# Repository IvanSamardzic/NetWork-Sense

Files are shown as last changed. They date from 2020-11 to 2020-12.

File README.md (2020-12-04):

## NetWork-Sense

* Low Power Consumption
* Energy Autonomy
* Wireless Communication Realisation Using Radio Vawes

### System Architecture

GitHub Logo

#### Arduino Nano Pin Configuration

```
const int redLed = 2;
const int greenLed = 3;
const int cePin = 7;
const int csnPin = 8;
const int trigPin = 9;
const int echoPin = 10;
const int mosiPin = 11;
const int misoPin = 12;
const int sckPin = 13;
```

#### ESP32 Pin Configuration

```
const int cePin = 4;
const int csnPin = 5;
const int mosiPin = 23;
const int misoPin = 19;
const int sckPin = 18;
```

#### Network Explanation

The node has the function of monitoring the presence of the object at an angle of 45 degrees, when the vessel / vehicle is recognized by a sensor, then this status change
message is sent to the main node of the sensor network (gateway) using a radio module operating at 2.4 GHz.

When the master node receives a state change message on one of its child nodes, then the gateway sends a request to the database to change the value that determines the
occupancy of the position in front of the sensor.

###### Connection to WiFi Network
```
WiFi.begin(ssid, password);
    Serial.println("Connecting");
    while (WiFi.status() != WL_CONNECTED) {
    delay(500);
    Serial.print(".");
    }
    Serial.println("");
    Serial.print("Connected to WiFi network with IP Address: ");
    Serial.println(WiFi.localIP());
    Serial.println();
    Serial.println();
    Serial.println();
}
```
The gateway is equipped with an ESP32 microcontroller that has the ability to connect to a WiFi network, communicates with the database by sending various HTTP requests.The
ability to send HTTP requests is possible if the HTTP Client is properly created to receive and send data to the HTTP Server.

###### HTTP Client Initialisation 
```
//Send an HTTP POST request every 10 minutes
    if ((millis() - lastTime) > timerDelay) {
    //Check WiFi connection status
    if (WiFi.status() == WL_CONNECTED) {
      HTTPClient http;
    }
    else {
      Serial.println("WiFi Disconnected");
    }
    // Measure the time the system tries to create HTTP Client or
    // time it has been created
    lastTime = millis();
    // Wait for 2000msec
    delay(2000);
  }

```

###### Sensor Data Acquisition And Conversion Into String

```
  digitalWrite(trigPin, LOW);
  delayMicroseconds(delayPeriod/5);
  digitalWrite(trigPin, HIGH);
  delayMicroseconds(delayPeriod);
  digitalWrite(trigPin, LOW);
  duration = pulseIn(echoPin, HIGH);
  distance = duration * conversionFactor;
  Serial.print("Distance: ");
  Serial.println(distance);
  if(distance < distanceLevel){
    digitalWrite(redLed, HIGH);
    digitalWrite(greenLed, LOW);
    isTaken = true;
  }
  else{
    digitalWrite(redLed, LOW);
    digitalWrite(greenLed, HIGH);
    isTaken = false;
  }
```

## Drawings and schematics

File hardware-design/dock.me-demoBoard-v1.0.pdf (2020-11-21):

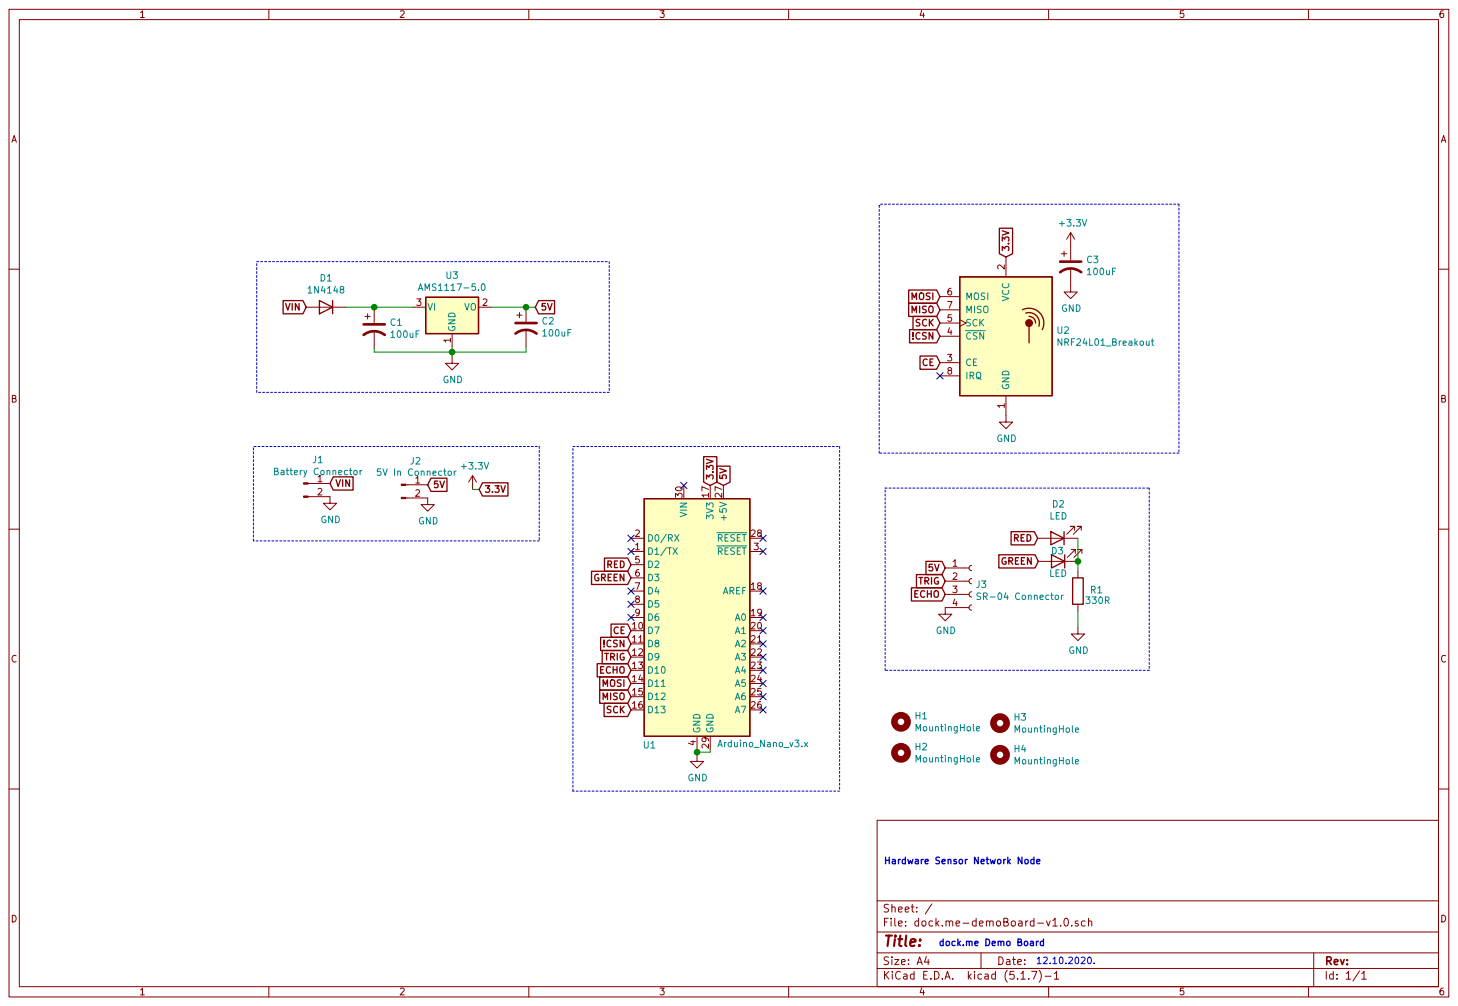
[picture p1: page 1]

12.10.2020. Hardware Sensor Network Node

dock.me Demo Board

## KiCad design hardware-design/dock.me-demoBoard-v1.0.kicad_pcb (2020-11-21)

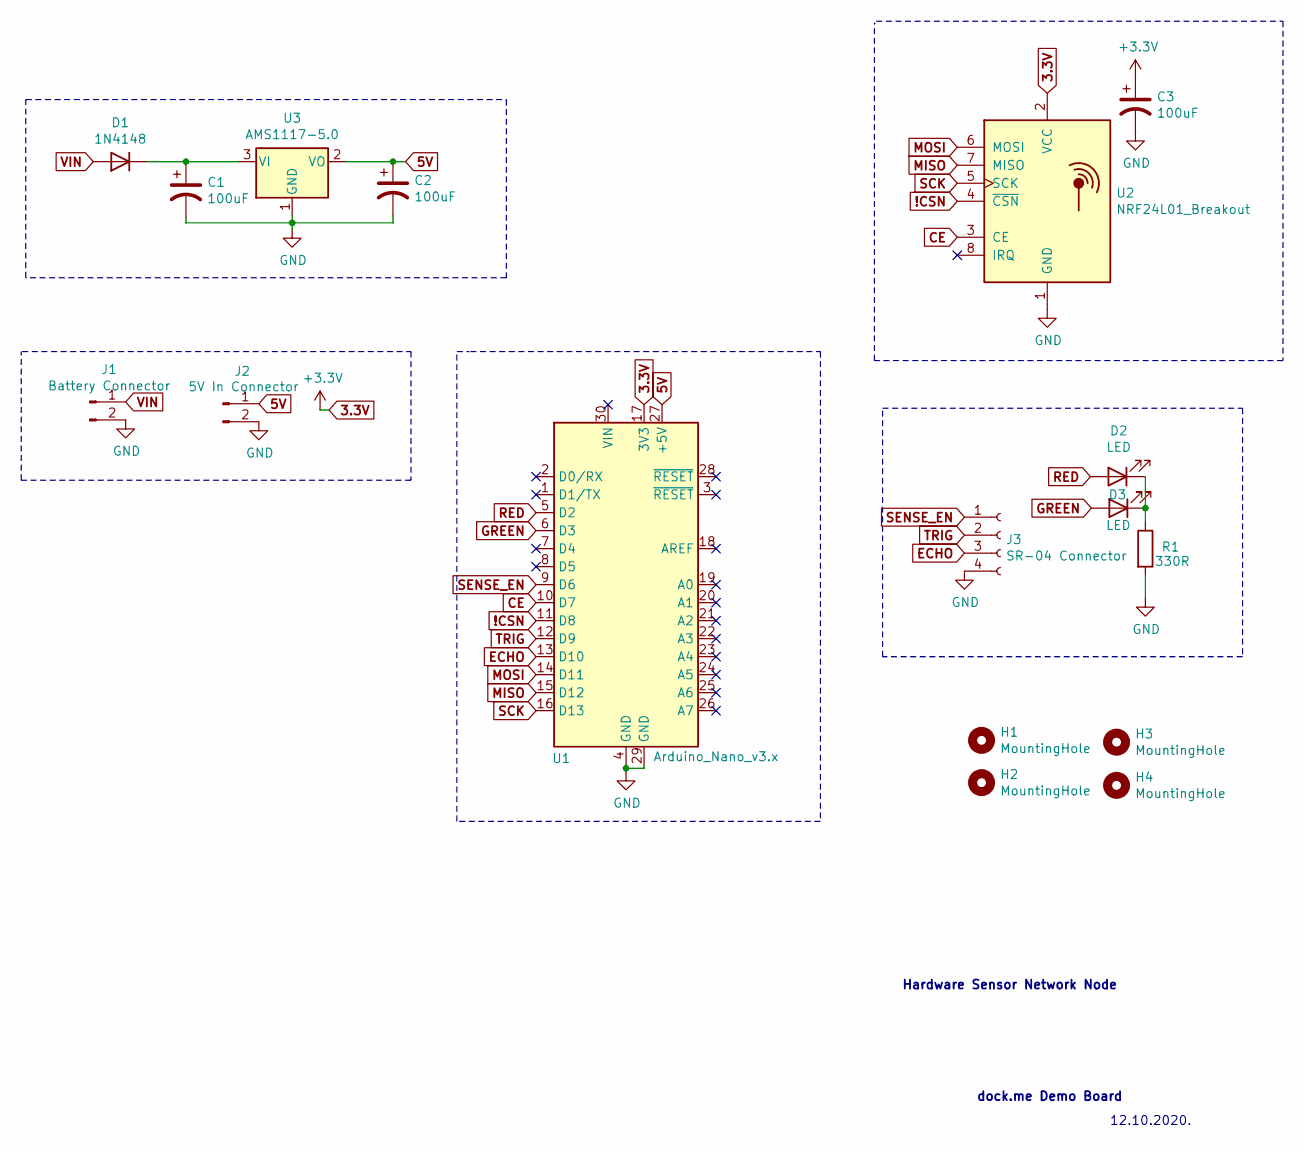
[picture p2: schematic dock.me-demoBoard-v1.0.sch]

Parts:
C1, C2, C3: 100uF; CP_Radial_D4.0mm_P1.50mm
D1: 1N4148; D_DO-35_SOD27_P7.62mm_Horizontal
D2, D3: LED; LED_D5.0mm
H1, H2, H3, H4: MountingHole; MountingHole_2.5mm
J1: Battery Connector; 1x02_5.08mm
J2: 5V In Connector; 1x02_5.08mm
J3: SR-04 Connector; PinSocket_1x04_P2.54mm_Vertical
R1: 330R; R_Axial_DIN0414_L11.9mm_D4.5mm_P15.24mm_Horizontal
U1: Arduino_Nano_v3.x; Arduino_Nano
U2: NRF24L01_Breakout; nRF24L01_Breakout
U3: AMS1117-5.0; SOT-223-3_TabPin2

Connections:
3.3V: C3.1, U1.17 (3V3), U2.2 (VCC)
5V: C2.1, J2.1, U1.27 (+5V), U3.2 (VO)
!CSN: U1.11 (D8), U2.4 (~CSN)
CE: U1.10 (D7), U2.3 (CE)
ECHO: J3.3, U1.13 (D10)
GND: C1.2, C2.2, C3.2, J1.2, J2.2, J3.4, R1.2, U1.4 (GND), U1.29 (GND), U2.1 (GND), U3.1 (GND)
GREEN: D3.2 (A), U1.6 (D3)
MISO: U1.15 (D12), U2.7 (MISO)
MOSI: U1.14 (D11), U2.6 (MOSI)
unnamed: C1.1, D1.1 (K), U3.3 (VI)
unnamed: D2.1 (K), D3.1 (K), R1.1
RED: D2.2 (A), U1.5 (D2)
SCK: U1.16 (D13), U2.5 (SCK)
SENSE_EN: J3.1, U1.9 (D6)
TRIG: J3.2, U1.12 (D9)
VIN: D1.2 (A), J1.1

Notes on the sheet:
dock.me Demo Board
12.10.2020.
Hardware Sensor Network Node

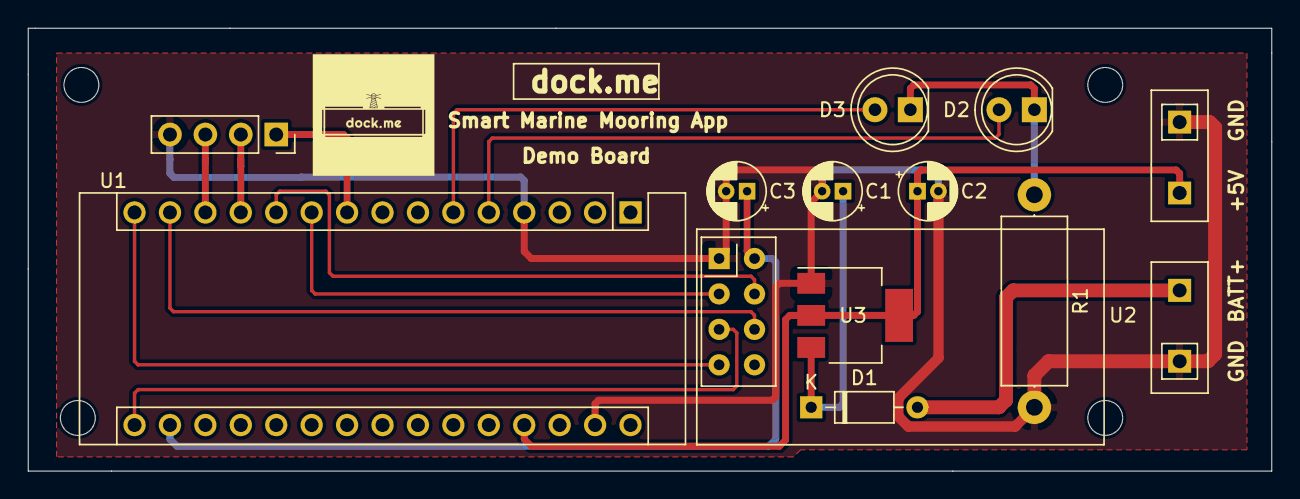
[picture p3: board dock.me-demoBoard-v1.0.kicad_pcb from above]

Board: 2 copper layers, 89.2 x 31.8 mm, 17 parts (0 on the bottom side), 16 nets.

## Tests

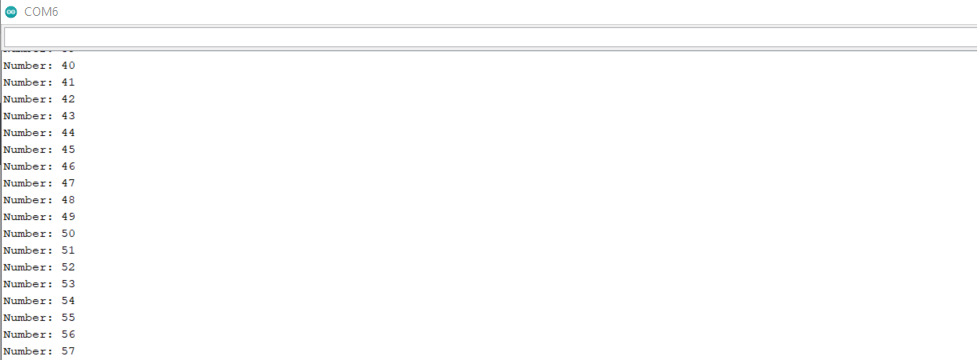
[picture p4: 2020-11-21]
hardware-tests/radio-module-testing/receiver-serial-monitor.png

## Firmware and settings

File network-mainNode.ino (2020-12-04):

// Libraries
#include <WiFi.h>
#include <HTTPClient.h>
#include <ArduinoJson.h>
#include <WiFiMulti.h>
#include <Arduino.h>
#include <SPI.h>
#include <nRF24L01.h>
#include <RF24.h>
#include <WiFiClientSecure.h>

// Pins declaration
const int cePin = 4;
const int csnPin = 5;
const int sckPin = 18;
const int misoPin = 19;
const int mosiPin = 23;

const int timeoutPeriod = 200;


const char* ssid = "Redmi";
const char* password = "174a4bf36308";
RF24 radio(cePin, csnPin);
const byte address[6] = "00001";

//Your Domain name with URL path or IP address with path
//https://dockme20201010041424.azurewebsites.net//api/Docks/dockNumber/true
const char* serverName = "https://dockme2.azurewebsites.net/api";

// the following variables are unsigned longs because the time, measured in
// milliseconds, will quickly become a bigger number than can be stored in an int.
unsigned long lastTime = 0;
// Timer set to 10 minutes (600000)
//unsigned long timerDelay = 600000;
// Set timer to 5 seconds (5000)
unsigned long timerDelay = 5000;

//Global variables definition
int distance;
int dockNumber = 1;
String isTakenString = "true";
bool isTaken = true;
String header;
String call = (String)dockNumber + "/" + isTaken;
String payload;

void setup() {
    Serial.begin(115200);
    // Deserialize the JSON document
    StaticJsonDocument<200> doc;
    DeserializationError error = deserializeJson(doc, payload);

    WiFi.begin(ssid, password);
    Serial.println("Connecting");
    while (WiFi.status() != WL_CONNECTED) {
    delay(500);
    Serial.print(".");
    }
    Serial.println("");
    Serial.print("Connected to WiFi network with IP Address: ");
    Serial.println(WiFi.localIP());
    Serial.println();
    Serial.println();
    Serial.println();
}

void loop() {
    SPI.begin();
    delay(10);
    radio.begin();
    radio.openReadingPipe(0, address);
    radio.setPALevel(RF24_PA_MIN);
    radio.startListening();
    delay(10);
  
    Serial.println("Radio Started...");
    Serial.println();
  
    if (radio.available()) {
      radio.read(&isTaken, sizeof(isTaken));
    }
  
    if (isTaken == true) {
      isTakenString = "true";
    }
    else {
      isTakenString = "false";
    }
  
    Serial.print("Message: ");
    Serial.println(isTakenString);
    delay(10);
    SPI.end();
    delay(10);
  
    StaticJsonDocument<200> doc;
    //Send an HTTP POST request every 10 minutes
    if ((millis() - lastTime) > timerDelay) {
    //Check WiFi connection status
    if (WiFi.status() == WL_CONNECTED) {
      HTTPClient http;


      // HTTP GET METHOD
      Serial.println("https://dockme2.azurewebsites.net/api/Docks/1");
      http.begin("https://dockme2.azurewebsites.net/api/Docks/1");
      http.addHeader("Content-Type", "application/json");
      int httpCode = http.GET();
      if (httpCode > 0) {
        Serial.print("[HTTPS]GET code: ");
        Serial.print(httpCode);
      }

      String payload = http.getString();
      Serial.println(payload);

      // Deserialize the JSON document
      DeserializationError error = deserializeJson(doc, payload);

      int jsonDockNumber = doc["dockNumber"];
      Serial.println(jsonDockNumber);

      String jsonIsTaken = doc["isTaken"];
      Serial.println(jsonIsTaken);

      String jsonIsReserved = doc["isReserved"];
      Serial.println(jsonIsReserved);

      Serial.println();

      // Free resources
      http.end();
      Serial.print("HTTP Closed");
      Serial.println();




      // HTTP PUT METHOD
      Serial.println("https://dockme2.azurewebsites.net/api/Docks/" + call);
      http.begin("https://dockme2.azurewebsites.net/api/Docks");
      http.addHeader("Content-Length", "0");
      http.addHeader("Content-Type", "application/json");
      String jsonPayload = "{'dockNumber': " + String(jsonDockNumber) + " ,'isTaken': " + String(isTakenString) + " ,'isReserved': " + String(true) + " }";
      Serial.println(jsonPayload);
      int httpResponseCode = http.PUT(jsonPayload);

      Serial.print("PUT Response Code: ");
      Serial.println(httpResponseCode);

      if (httpResponseCode < 0) {
        Serial.print("Error on sending PUT Request: ");
        Serial.println(httpResponseCode);
      }
      
      //Free resources
      http.end();
      Serial.print("HTTP Closed");
      Serial.println();
    }
    else {
      Serial.println("WiFi Disconnected");
    }
    lastTime = millis();
    delay(2000);
  }
}

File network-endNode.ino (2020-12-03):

// Libraries
#include <SPI.h>
#include <nRF24L01.h>
#include <RF24.h>
#include <avr/wdt.h>

// Pins declaration
const int redLed = 2;
const int greenLed = 3;
const int cePin = 7;
const int csnPin = 8;
const int trigPin = 9;
const int echoPin = 10;
const int mosiPin = 11;
const int misoPin = 12;
const int sckPin = 13;

// Variables declaration
int duration, distance;
const int delayPeriod = 10;
const int distanceLevel = 100;
const int timeoutPeriod = 200;
double conversionFactor = 0.017;
bool isTaken = false;


RF24 radio(cePin, csnPin); // CE, CSN
const byte address[6] = "00001";

void reboot() {
  wdt_disable();
  wdt_enable(WDTO_15MS);
  while (1) {}
}
void setup() {
  Serial.begin(115200);
  pinMode(redLed, OUTPUT);
  pinMode(greenLed, OUTPUT);
  pinMode(trigPin, OUTPUT);
  pinMode(echoPin, INPUT);
 
}

void loop() {
  delay(timeoutPeriod);
  digitalWrite(trigPin, LOW);
  delayMicroseconds(delayPeriod/5);
  digitalWrite(trigPin, HIGH);
  delayMicroseconds(delayPeriod);
  digitalWrite(trigPin, LOW);
  duration = pulseIn(echoPin, HIGH);
  distance = duration * conversionFactor;
  Serial.print("Distance: ");
  Serial.println(distance);
  if(distance < distanceLevel){
    digitalWrite(redLed, HIGH);
    digitalWrite(greenLed, LOW);
    isTaken = true;
  }
  else{
    digitalWrite(redLed, LOW);
    digitalWrite(greenLed, HIGH);
    isTaken = false;
  }
  
  
  radio.begin();
  radio.openWritingPipe(address);
  radio.setPALevel(RF24_PA_MIN);
  radio.stopListening();
  radio.write(&isTaken, sizeof(isTaken));
  Serial.print("Message: ");
  Serial.println(isTaken);
  reboot();
}
